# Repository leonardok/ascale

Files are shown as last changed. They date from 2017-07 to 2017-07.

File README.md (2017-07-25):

# ascale

[para português veja o final da página]

This project is a digital scale that can be used as a kitchen scale. The
original objective was to build a coffee brewing scale with a timer, more
or less a clone of the
[Hario Drip Scale](http://www.hario.jp/seihin/productgroup.php?group=VST-2000B).
While prototyping I was missing the LCD and some push buttons, so the thing
moved all to android.

The goal now `ascale` is to provide people an easy way for a kitchen scale DIY.

Inside this repository you will find tree parts:

- arduino project that contains the code to run inside an arduino
- android project with the UI to interact with the scale
- [TODO: ios project]

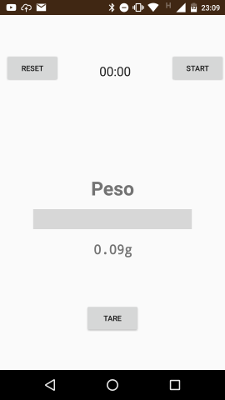
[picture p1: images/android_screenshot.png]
Android App

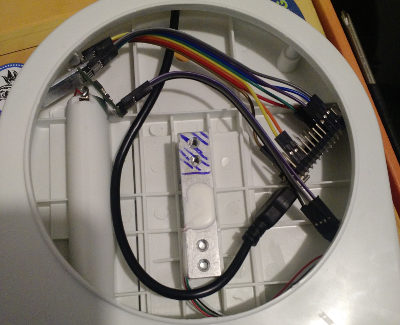
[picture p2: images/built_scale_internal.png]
Built Scale

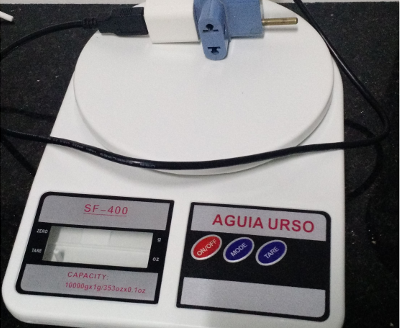
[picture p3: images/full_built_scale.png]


## Bill of materials

- Arduino.  I have used a [Freaduino Uno](https://www.elecfreaks.com/wiki/index.php?title=Freaduino_UNO)
  at first, it offers a lot of extra pins. In the final version I replaced with an
  [Arduino Nano](https://store.arduino.cc/usa/arduino-nano). You can use any
  that you have spare.

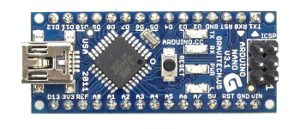
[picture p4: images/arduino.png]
Arduino
    

- [HX711](https://www.sparkfun.com/products/13879)

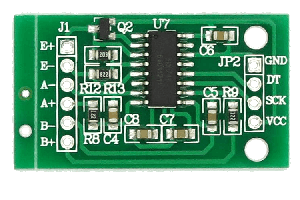
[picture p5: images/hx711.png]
hx711
  

- Bluetooth module [HC-05](https://www.amazon.com/s/ref=nb_sb_noss_2?field-keywords=hc-05)

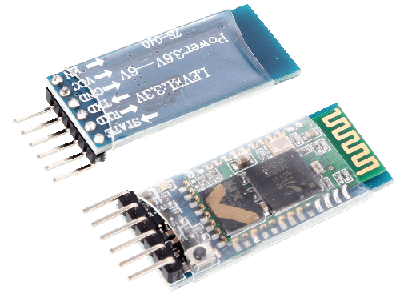
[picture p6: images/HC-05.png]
HC-05
  
- [Load Cell](https://www.sparkfun.com/products/13329) (you can also buy an
  off the shelf scale and dismantle it, if you want the casing too.)

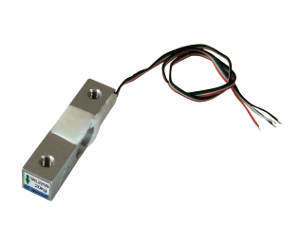
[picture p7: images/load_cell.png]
Load Cell
  

## Assembly

Vcc and GND are not specified, but of course you should connect to the Vcc and
GND on your arduino board.

| Load Cell | HX711 | - | HX711 | Arduino | - | HC-05 | Arduino |
|---|---|---|---|---|---|---|---|
| red | E+ | . | rx | D2 | . | rx | D11 |
| white | E- | . | tx | D3 | . | tx | D10 |
| black | A+ |
| green | A- |

#### How it is supposed to look:
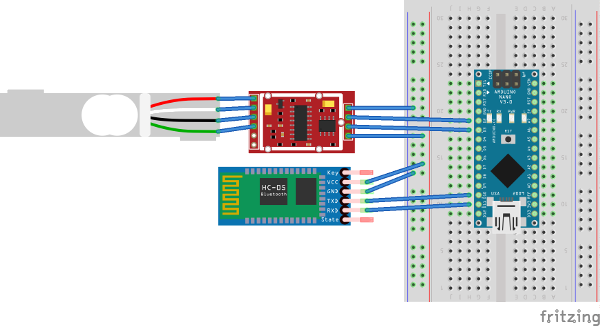
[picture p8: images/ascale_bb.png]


## Scale Message Protocol

As soon as you turn on the scale it is going to start sending messages through
bluetooth. The only thing you need to do is to pair and connect to the board,
as soon as you open your serial input stream in your client you will see theses
messages:

    // incoming data
    {'weight': '0.6441', 'unit': 'g'}

And this is all you have to interpret if you build a client.

The `tare` function is through sending `"t"` to the client outstream channel.

# Em Português

### Lista de Materiais

Para este projeto você vai precisar dos itens abaixo. Todos eles podem ser
encontrados facilmente no Mercado Livre e nenhuma solda é necessária.

- arduino (R$ 20)
- driver para celula de carga, chamado HX711 (R$ 8)
- célula de carga de 2 kg (R$ 24) (pode ser usado de outras cargas, mas muda a precisão)
  para o meu projeto comprei uma balanca chinesa de R$ 25 reais, então aproveitei o
  chassi da balanca
- módulo bluetooth (HC-05 ou HC-06) (R$ 25)

Total em em torno de R$ 80.

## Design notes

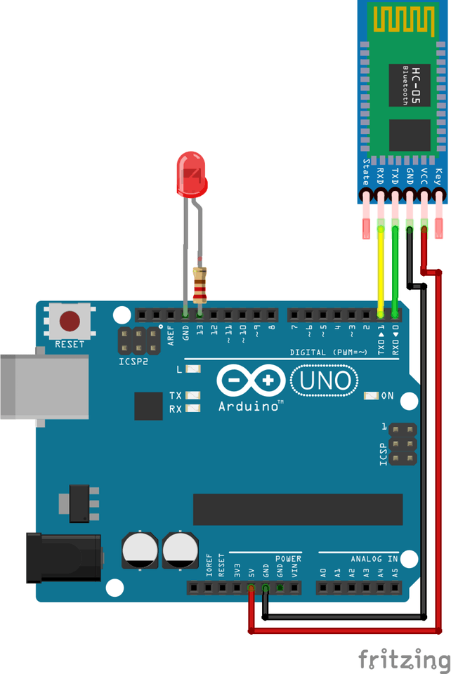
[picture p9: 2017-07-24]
docs/bt_connection.png

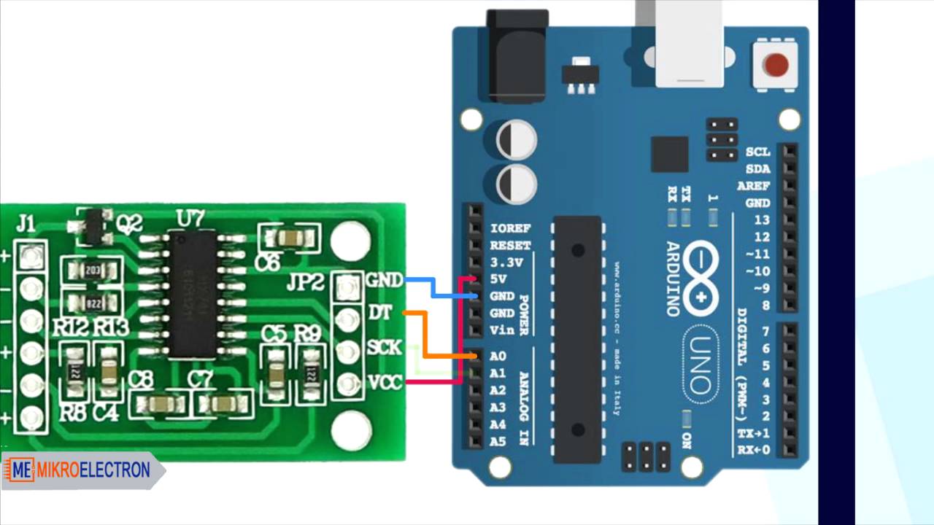
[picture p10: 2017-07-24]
docs/maxresdefault.jpg

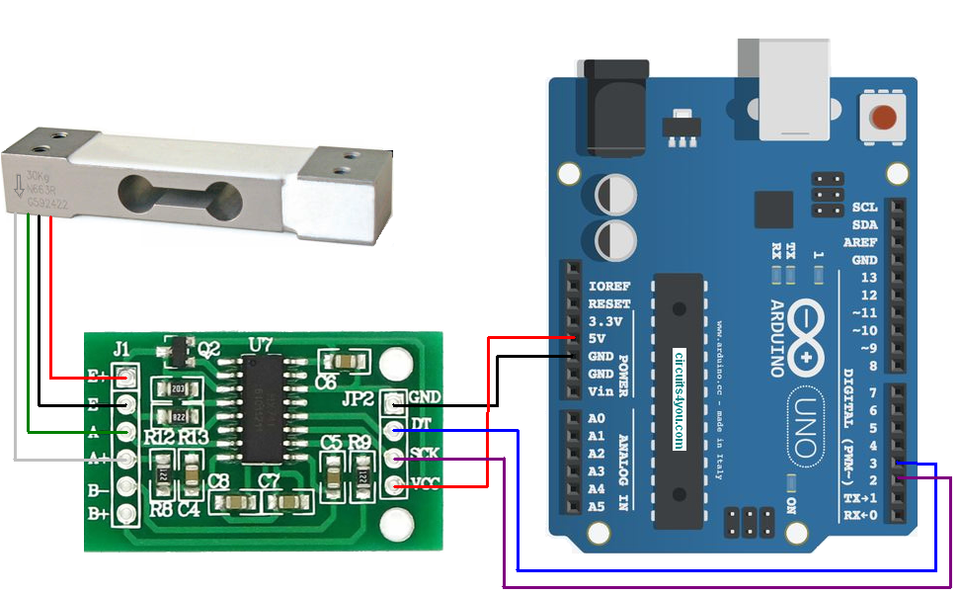
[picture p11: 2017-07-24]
docs/load_cell_interface_arduino.png

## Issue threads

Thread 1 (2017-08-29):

App not able to connect to bluetooth module?

MuckYu, 2017-08-29:
Hi, I imported the android folder into android studio and build an apk, which I installed on my phone.

The app opens fine and loads the "Find scale" screen.

However no bluetooth module is showing up. (I tested both, HC-05 and HC-06)
I can connect to them via other app.

Am I missing something on how to properly connect it with the app?

leonardok, 2017-08-29:
Does the arduino looks ok? Can you see the bluetooth in the android bluetooth scanner?

MuckYu, 2017-08-30:
Yes the arduino and the HC-05 module are both working fine. I am able to find it in the android bluetooth list.

I also tried several HC-05 arduino related apps on the playstore and they connect to it.

Maybe I am doing something wrong with the .apk export? Any settings I should be aware of?

I am using android 6.0.1

MuckYu, 2017-08-30:
Yes the bluetooth module is showing up in the BT list on my android. I can
also connect to it via several HC-05 arduino apps from the playstore.

But in this app the list is empty.

Maybe I did something wrong when I exported it to an .apk? Any special
settings I should be aware of?

On 30 Aug 2017 7:23 a.m., "Leonardo Korndörfer" <notifications@github.com>
wrote:

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

MuckYu, 2017-08-30:
Using android 6.0.1

On 30 Aug 2017 11:20 a.m., wrote:

Yes the bluetooth module is showing up in the BT list on my android. I can
also connect to it via several HC-05 arduino apps from the playstore.

But in this app the list is empty.

Maybe I did something wrong when I exported it to an .apk? Any special
settings I should be aware of?

On 30 Aug 2017 7:23 a.m., "Leonardo Korndörfer" <notifications@github.com>
wrote:

Does the arduino looks ok? Can you see the bluetooth in the android
bluetooth scanner?

—
You are receiving this because you authored the thread.
Reply to this email directly, view it on GitHub
<https://github.com/leonardok/ascale/issues/1#issuecomment-325832490>, or mute
the thread
<https://github.com/notifications/unsubscribe-auth/AdLf1Hy90S2FgDCps1l1ABiSisuHGfzrks5sdJ1hgaJpZM4PF_06>
.

leonardok, 2017-08-30:
The list has a pulldown refresh. Did you try to pull it down to refresh? It is obvious but I remember now that I haven't put any kind of visual indication that the blueooth devices list has pulldown refresh.
Can you connect your phone to Android Studio and check the console output for any errors?

It doesn't looks like you are doing something wrong...

In `FindScaleFragment.java`, in the `refreshDeviceList` method there is a debug line for when it finds a device.

MuckYu, 2017-08-30:
Yes, I tried the pull down menu already.

I have now connected my phone to the android studio console.

Surprisingly in the android monitor tab I see this line:

> 08-31 01:03:32.704 21783-29221/me.leok.scaleduino V/FindScaleFragment: Found device: HC-05
08-31 01:03:32.706 21783-29221/me.leok.scaleduino V/FindScaleFragment: Ended device scan

But on the phone it's empty.
Any ideas?

leonardok, 2017-08-30:
Oh! Probably I haven't updated my arduino code...
The problem is that there is a condition in the android code to show only devices with "ascale" as name. Do you see in lines 155 though 157:

```
if (scaleBluetoothName.toString().equals(device.getName())) {
    scaleDevices.add(device);
}
```
`scaleBluetoothName` is defined to "ascale". Can you remove that condition so `scaleDevices.add(device);` is called to all BT devices?

MuckYu, 2017-08-31:
That worked, thanks a lot!

leonardok, 2017-08-31:
Sure! I will leave this open so I can change the code later.
Any other thing just drop me a message!

MuckYu, 2017-08-31:
Okay I got another problem I think.

Now I am connected to the bluetooth module, but I don't get any value on the app from the scale.

In the arduino console I get the data just fine. Is there still something I have to adjust in the code?

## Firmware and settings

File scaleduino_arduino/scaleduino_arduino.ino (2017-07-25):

/*
 * circuits4you.com
 * 2016 November 25
 * Load Cell HX711 Module Interface with Arduino to measure weight in Kgs
 Arduino 
 pin 
 2 -> HX711 CLK
 3 -> DOUT
 5V -> VCC
 GND -> GND

 Most any pin on the Arduino Uno will be compatible with DOUT/CLK.
 The HX711 board can be powered from 2.7V to 5V so the Arduino 5V power should be fine.
*/

#include "HX711.h"  //You must have this library in your arduino library folder
#include <SoftwareSerial.h>
#include "RunningAverage.h"

#define DOUT  3
#define CLK  2

SoftwareSerial BT(10, 11);
RunningAverage myRA(15);
int samples = 0;

HX711 scale(DOUT, CLK);

//Change this calibration factor as per your load cell once it is found you many need to vary it in thousands
// float calibration_factor = -96650; //-106600 worked for my 40Kg max scale setup 
float calibration_factor = -344650;

//=============================================================================================
//                         SETUP
//=============================================================================================
void setup() {
  delay(250);
  
  Serial.begin(9600);

  BT.begin(9600);
  
  Serial.println("HX711 Calibration");
  Serial.println("Remove all weight from scale");
  Serial.println("After readings begin, place known weight on scale");
  Serial.println("Press a,s,d,f to increase calibration factor by 10,100,1000,10000 respectively");
  Serial.println("Press z,x,c,v to decrease calibration factor by 10,100,1000,10000 respectively");
  Serial.println("Press t for tare");
  scale.set_scale();
  scale.tare(); //Reset the scale to 0

  long zero_factor = scale.read_average(); //Get a baseline reading
  Serial.print("Zero factor: "); //This can be used to remove the need to tare the scale. Useful in permanent scale projects.
  Serial.println(zero_factor);
}

//=============================================================================================
//                         LOOP
//=============================================================================================
void loop() {
  // scale.set_scale(calibration_factor); //Adjust to this calibration factor
  scale.set_scale(calibration_factor);

  float load_cell_data = scale.get_units();

  // this is to give grams precision, so now it goes from 0 to 10000 (10kg) grams
  load_cell_data = load_cell_data*1000;

  if (load_cell_data < 0) {
    load_cell_data = +0;
  }

  myRA.addValue(load_cell_data);
  samples++;

  float smotthed_load_value = myRA.getAverage();
  
  String data = String("{") + "'weight': '" + String(smotthed_load_value, 4) + "', 'unit': 'g'}";
  BT.println(data);
  Serial.println(data);

  // read bluetooth commands
  if (BT.available()) {
    char command = BT.read();
    
    if(command == 't') {
      Serial.println("tared");      
      scale.tare();  //Reset the scale to zero
    }
  }

  if(Serial.available()) {
    char temp = Serial.read();
    
    if(temp == '+' || temp == 'a')
      calibration_factor += 10;
    else if(temp == '-' || temp == 'z')
      calibration_factor -= 10;
    else if(temp == 's')
      calibration_factor += 100;  
    else if(temp == 'x')
      calibration_factor -= 100;  
    else if(temp == 'd')
      calibration_factor += 1000;  
    else if(temp == 'c')
      calibration_factor -= 1000;
    else if(temp == 'f')
      calibration_factor += 10000;  
    else if(temp == 'v')
      calibration_factor -= 10000;  
    else if(temp == 't') {
      Serial.println("tared");
      scale.tare();  //Reset the scale to zero
    }
  }
}
//=============================================================================================

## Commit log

2017-07-24 adding chrono
    [ascale.fzz]
2017-07-25 Adding tare button function
2017-07-25 Refactoring scale class and renamed arduino ini file
2017-07-25 Updating README
    [ascale.fzz]
